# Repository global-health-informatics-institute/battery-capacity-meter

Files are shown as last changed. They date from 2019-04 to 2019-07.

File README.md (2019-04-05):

# battery-capacity-meter

### Data from previous runs

Connect without any load. The BCM will go into passive mode and log data form the previous 9 runs together with information about the current current sensor calibration.

After the calibration data the last up to 9 runs are displayed. Each line shows the results from one run:

* startupCounter: runtime in minutes | measured mAh or Ah

### Measuring battery capacity

If a load is detected during startup, the BCM switches into measuring mode. It will take one minute before the first reading is displayed on the screen. From then every minute an intermediate result will be shown until the LVD cuts out.

Note that with +/- 31 Amps current sensor, a smaller load may not be properly be detected. Also make sure that the calibration (esp offset for the 0 value of the coded raw value) somehow matches.

### Calibration 

The calibration is necessary if a change in the layout is done (other current sensor, other Arduino board) as the sketch is written to the specific values of these specific components and can/will change with other components (mostly internal voltage regulator of the Arduino and wiring). This diagnostic data is printed on the screen with the prefix "no load":

* mA: current measured load (should oscillate around 0)
* rc: The raw value as read by the analog input (provided by the current sensor). Usually this is around 1024/2 and determines the 0 mA range. The rc value is the Raw values as currently Coded in the sketch. Should match rm.
* rm: The above raw value as currently delivered by the current sensor. Should match rc.
* vc: The currently coded reference voltage of the sketch as seen by the current sensor. Should be verified with an external voltmeter directly from the current sensor ('inner' GND pin and 'middle' V pin). CAREFUL to not short these 2 pins as they fry the Arduino and potentially other components.

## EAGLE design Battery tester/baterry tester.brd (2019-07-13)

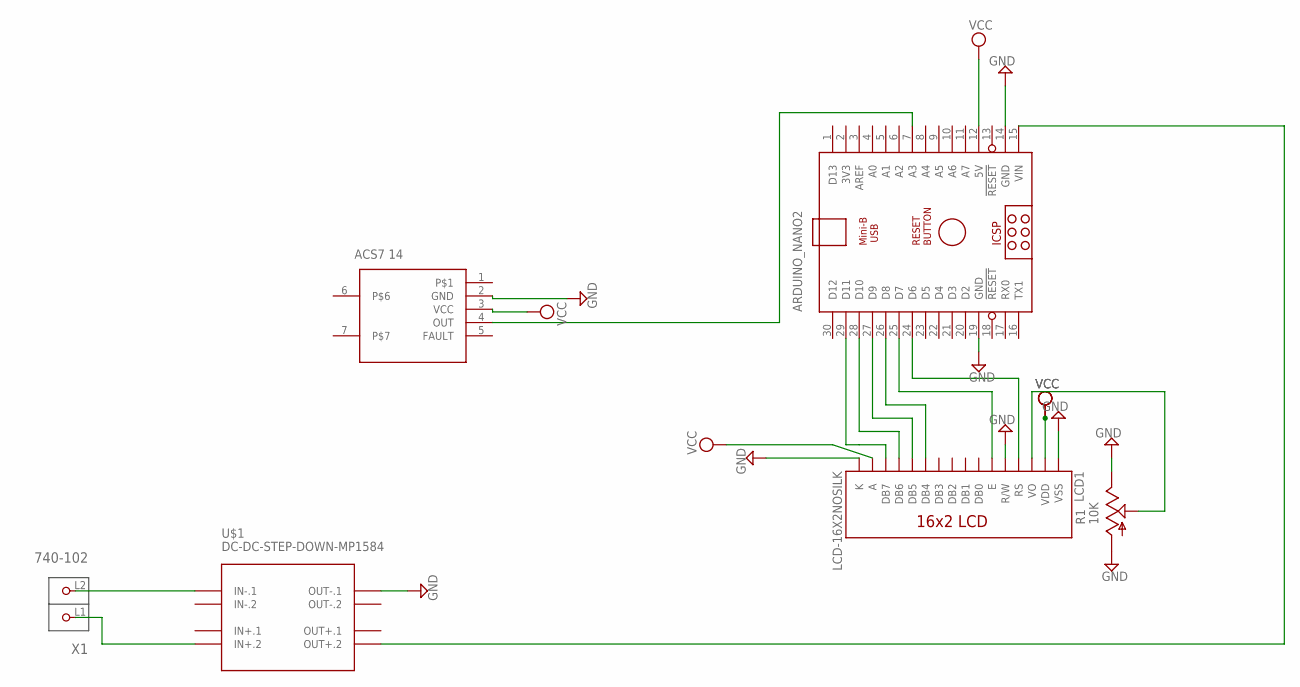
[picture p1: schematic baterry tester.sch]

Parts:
ARDUINO_NANO2: ARDUINO_NANO
LCD1: LCD-16X2NOSILK; LCD-16X2_NOSILK
R1: 10K; PT-10
U$1: DC-DC-STEP-DOWN-MP1584
U$3: ACS714EGHII-ACS714; ACS714E
X1: 740-102; P-740-102

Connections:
GND: ARDUINO_NANO2.14 (GND), ARDUINO_NANO2.19 (GND), LCD1.1 (VSS), LCD1.5 (R/W), LCD1.16 (K), R1.A, R1.E, U$1.OUT-.1, U$3.2 (GND)
unnamed: LCD1.3 (VO), R1.S
unnamed: ARDUINO_NANO2.29 (D11), LCD1.14 (DB7)
unnamed: ARDUINO_NANO2.28 (D10), LCD1.13 (DB6)
unnamed: ARDUINO_NANO2.27 (D9), LCD1.12 (DB5)
unnamed: ARDUINO_NANO2.26 (D8), LCD1.11 (DB4)
unnamed: ARDUINO_NANO2.25 (D7), LCD1.6 (E)
unnamed: ARDUINO_NANO2.24 (D6), LCD1.4 (RS)
unnamed: ARDUINO_NANO2.7 (A3), U$3.4 (OUT)
unnamed: ARDUINO_NANO2.15 (VIN), U$1.OUT+.2
unnamed: U$1.IN-.1, X1.L2 (P2)
unnamed: U$1.IN+.2, X1.L1 (P1)
VCC: ARDUINO_NANO2.12 (5V), LCD1.2 (VDD), LCD1.15 (A), U$3.3 (VCC)

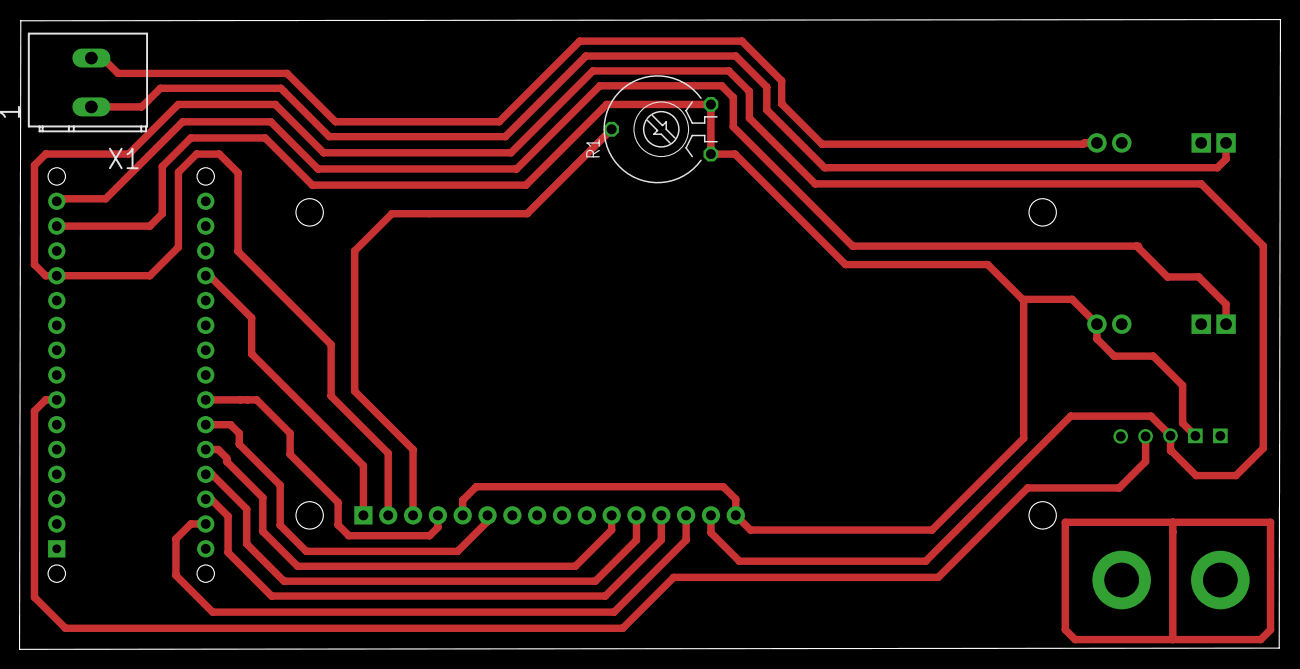
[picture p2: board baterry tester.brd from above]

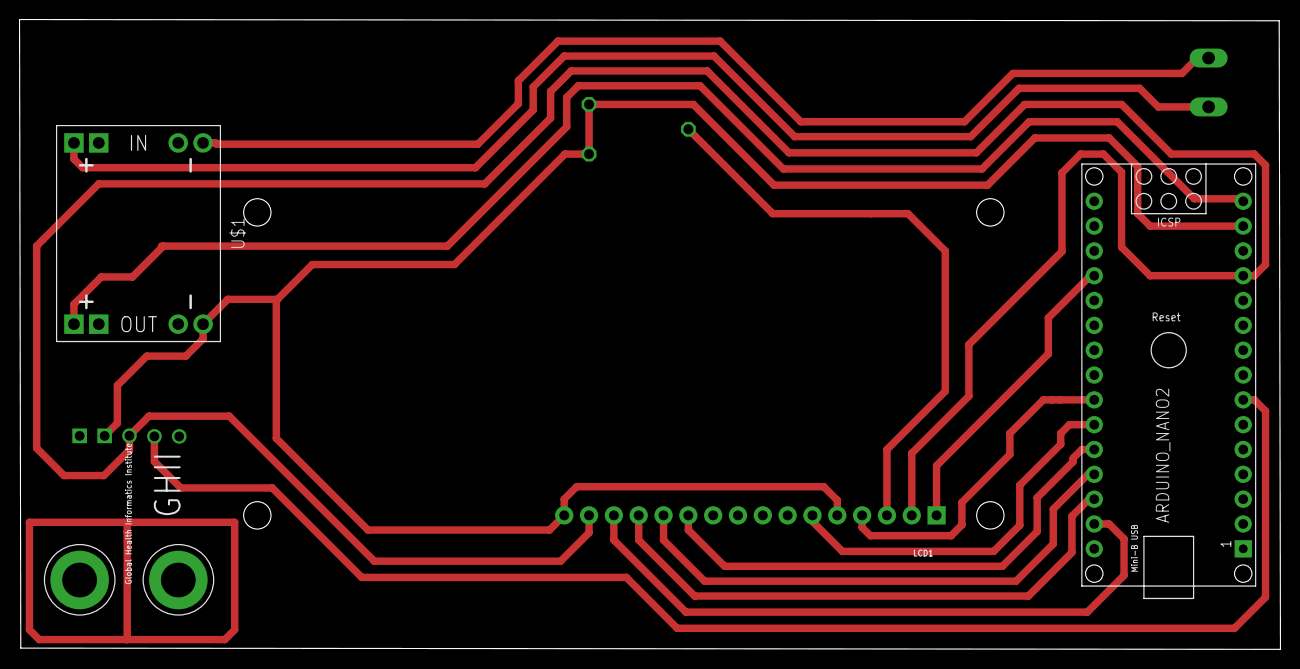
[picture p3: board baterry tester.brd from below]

Board: 2 copper layers, 129.0 x 64.4 mm, 6 parts (4 on the bottom side), 13 nets.

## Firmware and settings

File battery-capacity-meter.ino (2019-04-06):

/*
 * Battery Capacity Meter
 * 
 * Connect to battery and hook up a load. It will save the last 10 runs in EEPROM
 * (runtime in minutes plus accumulated AmpHours). Upon start it will either start 
 * a new run (when a load is detected) or simply cycle through the results of the
 * last 10 runs.
 */
// Arduino Nano
// Processor ATmega328 (Old Bootloader)

#include <EEPROM.h>
#include <LiquidCrystal.h>
#include <SoftwareSerial.h>

LiquidCrystal lcd(6, 7, 8, 9, 10, 11);
//LiquidCrystal lcd(2, 3, 4, 5, 11, 12);
const byte ACS711_PIN = A3;
//const int ACS711_VOLTAGE_REFERENCE = 4780;
const int ACS711_VOLTAGE_REFERENCE = 4990;
//const int ACS711_ZERO_LOAD_OFFSET = 512;
const int ACS711_ZERO_LOAD_OFFSET = 518;

//const byte LCD_TX = 9; // D9
//const byte LCD_RX = 6; // not connected anywhere
//SoftwareSerial myLcdSerial =  SoftwareSerial(LCD_RX, LCD_TX);

/*
 * EEPROM layout: 
 *  - one byte startup counter at eepromStartupCounterAddress
 *  - afterwards for each run 
 *     - 2 bytes (unsinged int) for runtime in minutes
 *     - 4 bytes (long) for milliamp hours
    EEPROM  variable  slot
    0   startupCounter  
    1   runtime1  0
    2   runtime2  
    3   mah1  
    4   mah2  
    5   mah3  
    6   mah4  
    7   runtime1  1
    8   runtime2  
    9   mah1  
    10    mah2  
    11    mah3  
    12    mah4  
    ... 
 */
const int eepromStartupCounterAddress=0;

byte eepromSlotForStartup;
unsigned int currentRuntimeInMinutes;
long previousMilliAmpMinutes;

// ------------------------ iteadstudio lcd -------------
// https://www.itead.cc/blog/uart-serial-lcd-module

void setupLcd()
{
    lcd.begin(16, 2);
 // pinMode(LCD_TX, OUTPUT); // Arduino's Tx as transmitter to LCD
  //pinMode(LCD_RX, INPUT); //
  Serial.begin(9600);
 lcd.clear();
 // delay(10);
 //lcd.print("sb0;"); // set backlight, 0=off, 1=on (sb)
  //delay(10);
lcd.setCursor(0,0);
 
 lcd.print("mars monitoring");
 
 lcd.setCursor(0,1);
 // delay(10);
 lcd.print("Battery Capacity");
 // delay(10);
  delay(2000);
  lcd.clear();
}

void printLcdSketchConfig(int rawValueCoded, int rawValueMeasured, int referenceVoltageCoded, int milliAmps) {
 lcd.clear();
 // delay(10);
// lcd.print("sb1;"); // set backlight, 0=off, 1=on (sb)
 // delay(10);
lcd.setCursor(0,0); //set coordinate (col 0,row 0)
 // delay(10);
 lcd.print("no load|mA");
 lcd.print(milliAmps);
 ////lcd.print(";");
 // delay(10);
 lcd.setCursor(0,0); //set coordinate (col 0,row 0)
 // delay(10);
// //lcd.print("ss");
 lcd.print("rc");
 lcd.print(rawValueCoded);
 lcd.print("rm");
 lcd.print(rawValueMeasured);
 lcd.print("vc");
 lcd.print(referenceVoltageCoded);
 //lcd.print(";");
 // delay(10);
}

void printLcdHistoricRun(byte startupCounter1, unsigned int runtimeInMins1, long milliampHours1, byte startupCounter2, unsigned int runtimeInMins2, long milliampHours2) {
 lcd.clear(); //lcd.clear():
 // delay(10);
lcd.setCursor(0,0); //set coordinate (col 0,row 0)  //lcd.setCursor(0,0);
 // delay(10);
// //lcd.print("ss");
 
 lcd.print("R");
 lcd.print(startupCounter1);
 lcd.print("|");
 lcd.print(runtimeInMins1);
 lcd.print("min|");
  if (milliampHours1 >= 1000) {
   lcd.print((int) milliampHours1 / 1000);
   lcd.print("Ah");
  } else {
   lcd.print(milliampHours1);
   lcd.print("mAh");
  }
 // delay(10);
 lcd.setCursor(0,1); //set coordinate (col 0,row 1)
 // delay(10);
// //lcd.print("ss");
 
 lcd.print("R");
 lcd.print(startupCounter2);
 lcd.print("|");
 lcd.print(runtimeInMins2);
 
 lcd.print("min|");
  if (milliampHours2 >= 1000) {
   lcd.print((int) milliampHours2 / 1000);
   lcd.print("Ah");
  } else {
   lcd.print(milliampHours2);
   lcd.print("mAh");
  }
 // delay(10);
}

void printLcdCurrentRun(byte startupCounter, unsigned int runtimeInMins, long milliampHours, int milliamps) {
 lcd.clear();
 // delay(10);
   int rawValue = sampleAnalogRead(ACS711_PIN, 40, 10);

lcd.setCursor(0,0); //set coordinate (col 0,row 0)
 // delay(10);
  //lcd.print("ss");
 lcd.print("Run");
 lcd.print(startupCounter);
 lcd.print(" | ");
 lcd.print(runtimeInMins);
 lcd.print("min");
 // delay(10);
 lcd.setCursor(0,1); //set coordinate (col 0,row 1)
 // delay(10);
 ////lcd.print("ss");
 lcd.print(milliamps);
 lcd.print("mA");
 lcd.print("| ");
  if (milliampHours >= 1000) {
    // lcd.setCursor(0,1);
   lcd.print( milliampHours / 1000);
   lcd.print("Ah");
  } else {
   lcd.print(milliampHours);
   lcd.print("mAh");
  }
  
 //// delay(10);

  if (rawValue > 507 && rawValue < 520) {
    // no load detected, print diagnostic and historic values
    while (true) {  
      lcd.setCursor(0,0); 
      lcd.print("LOAD WENT OFF AT.. ");
       lcd.setCursor(0,1); 
       lcd.print(runtimeInMins);
 lcd.print("min");
     
 //lcd.print(milliamps);
 //lcd.print("mA");
 lcd.print(" | ");
  if (milliampHours >= 1000) {
    //lcd.print("|"); 
   lcd.print( milliampHours / 1000);
   lcd.print("Ah");
  
  }
  else {
    lcd.print(" | ");
   lcd.print(milliampHours);
   lcd.print("mAh");
  }
           }}
    
delay(10000);
}

void printLcdWait() {
 //lcd.clear();
 // delay(10);
lcd.setCursor(0,0); //set coordinate (col 0,row 0)
 // delay(10);
 lcd.print("Wait 1 minute");
 // delay(10);
 lcd.setCursor(0,1); //set coordinate (col 0,row 1)
 // delay(10);
 lcd.print("Measuring...");
 // delay(10);
}

// ---------------- Current sensing ACS 711 -------------

// https://www.pololu.com/product/2452
int pololuAcs711DcMilliAmps(int analogInputPin, int mVReference, int zeroLoadOffset) {

  // reference voltage, should be 5 V, but can vary a bit
  // with my MacBookPro and Leonardo via USB it is 5110
  //const int mVReference = 5110;

  // 36.7 * (voltage / mVReference) - 18.3

  // 136 mV / Amp for +/- 15 A version, depending on mVRef
  // 68 mV / Amp for +/- 31 A version, depending on mVRef
  const int mVperAmp = 68 ;
  
  int rawValue = sampleAnalogRead(analogInputPin, 40, 10);
  float voltage = ((rawValue - zeroLoadOffset) / 1023.0) * mVReference;
  float mamps = voltage / mVperAmp;
  return (int) (mamps * 1000);
}

int sampleAnalogRead(int analogInputPin, int sampleSize, int delayPeriod) {
  long rawValue = 0;
  int in = 0;
  for (int i = 0; i < sampleSize; i++) {
    in = analogRead(analogInputPin);
    //Serial.print(" ");
    //Serial.print(in);
    rawValue += in;
    delay(delayPeriod);
  }
  int rawValueAvg = (long) rawValue / sampleSize;
  //Serial.print(": ");
  //Serial.println(rawValueAvg);
  return rawValueAvg;
}

// ------------------------------------------
void setup() {
  while (!Serial) {
    delay(1);  // for Leonardo/Micro/Zero
  }
  Serial.begin(9600);
  Serial.println("setup");

  //internalEepromClear();
  //delay(60000);
  
  printInternalEeprom();
  setupLcd();
 
  int rawValue = sampleAnalogRead(ACS711_PIN, 40, 10);
  int milliAmps = -1;
  Serial.println("raw value");
  Serial.println(rawValue);
  
  //  if (false) { // use this to enforce logging of current config values
  if (rawValue > 507 && rawValue < 520) {
    // no load detected, print diagnostic and historic values
    while (true) {
      rawValue = sampleAnalogRead(ACS711_PIN, 40, 10);
      milliAmps = pololuAcs711DcMilliAmps(ACS711_PIN, ACS711_VOLTAGE_REFERENCE, ACS711_ZERO_LOAD_OFFSET);

      Serial.print("Analog input no load reference value: ");
      Serial.print("Used (hardcoded): ");
      Serial.print(ACS711_ZERO_LOAD_OFFSET);
      Serial.print(" - Current reading: ");
      Serial.println(rawValue);
      Serial.print("Reference voltage of current sensor (hardcoded): ");
      Serial.println(ACS711_VOLTAGE_REFERENCE);
      Serial.print("Current milliAmps: ");
      Serial.println(milliAmps);
    
      // simply cycle forever to prevent invocation of loop
      printLcdSketchConfig(ACS711_ZERO_LOAD_OFFSET, rawValue, ACS711_VOLTAGE_REFERENCE, milliAmps);
      delay(5000);
      int startups = readStartupCounter();
      for (int i = startups; i > 0 && (i > (startups-10)) ; i-=2) {
        printLcdHistoricRun(
          i, 
          readRuntimeCounterForStartup(i % 10), 
          readMilliAmpHoursForStartup(i % 10), 
          i-1, 
          readRuntimeCounterForStartup((i-1) % 10), 
          readMilliAmpHoursForStartup((i-1) % 10)
        );
        delay(5000);
      }
    }
  }

  // make sure not more than 9 runs are stored
  eepromSlotForStartup = (readStartupCounter() + 1) % 10;
  if (readStartupCounter() < 9) {
    writeStartupCounter(readStartupCounter() + 1);
  } else {
    writeStartupCounter(1);
  }
  
  currentRuntimeInMinutes = 0;
  writeRuntimeCounterForStartup(eepromSlotForStartup, currentRuntimeInMinutes);

  printLcdWait();
  Serial.println("Setup done");
}

void loop() {
  Serial.println("loop");
  delay(60000);
   

  

  currentRuntimeInMinutes++;
  writeRuntimeCounterForStartup(eepromSlotForStartup, currentRuntimeInMinutes);  

  int milliAmps;
  milliAmps = pololuAcs711DcMilliAmps(ACS711_PIN, ACS711_VOLTAGE_REFERENCE, ACS711_ZERO_LOAD_OFFSET);
  long previousMilliAmpHours;
  previousMilliAmpHours = readMilliAmpHoursForStartup(eepromSlotForStartup);
  long currentMilliAmpHours;
  currentMilliAmpHours = previousMilliAmpHours + (milliAmps / (long) 60);
  writeMilliAmpHoursForStartup(eepromSlotForStartup, currentMilliAmpHours);
  
  printLcdCurrentRun(readStartupCounter(), currentRuntimeInMinutes, currentMilliAmpHours, milliAmps);
  
  Serial.print("startupCounter: ");
  Serial.print(readStartupCounter());
  Serial.print(" - eepromSlot: ");
  Serial.print(eepromSlotForStartup);
  Serial.print(" - currentRuntime: ");
  Serial.print(currentRuntimeInMinutes);
  Serial.print(" - current milliAmps: ");
  Serial.print(milliAmps);
  Serial.print(" - milliAmpHours: ");
  Serial.print(currentMilliAmpHours);
  Serial.println();

    }


// ------------- EEPROM -------------------

void printInternalEeprom() {
  Serial.println("Previous runtimes");
  int startups = readStartupCounter();
  for (int i = startups; i > 0 && (i > (startups-10)) ; i--) {
    Serial.print("Startup: ");
    Serial.print(i);
    
    Serial.print(" | Mins: ");
    unsigned int runtimes;
    runtimes = readRuntimeCounterForStartup((i % 10));
    Serial.print(runtimes);
    
    Serial.print(" | Milliamphours: ");
    long mah;
    mah = readMilliAmpHoursForStartup((i % 10));
    Serial.print(mah);
    Serial.println();
  }
}

byte readStartupCounter() {
  return EEPROM.read(eepromStartupCounterAddress);
}

void writeStartupCounter(byte counter) {
  EEPROM.write(eepromStartupCounterAddress, counter);
}

unsigned int readRuntimeCounterForStartup(byte counter) {
  unsigned int minutes;
  EEPROM.get((counter * 6) + 1, minutes);
  return minutes;
}

void writeRuntimeCounterForStartup(byte counter, unsigned int  minutes) {
  EEPROM.put((counter * 6) + 1, minutes);
}

long readMilliAmpHoursForStartup(byte counter) {
  long mah;
  EEPROM.get((counter * 6) + 3, mah);
  return mah;
}

void writeMilliAmpHoursForStartup(byte counter, long mah) {
  EEPROM.put((counter * 6) + 3, mah);
}

void internalEepromClear() {
  for (int i = 0 ; i < EEPROM.length() ; i++) {
    EEPROM.write(i, 0);
  }
  Serial.println("eeprom cleared");
}

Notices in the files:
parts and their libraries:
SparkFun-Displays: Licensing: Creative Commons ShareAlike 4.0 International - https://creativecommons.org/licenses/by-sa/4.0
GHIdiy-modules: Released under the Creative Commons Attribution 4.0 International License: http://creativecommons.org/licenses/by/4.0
